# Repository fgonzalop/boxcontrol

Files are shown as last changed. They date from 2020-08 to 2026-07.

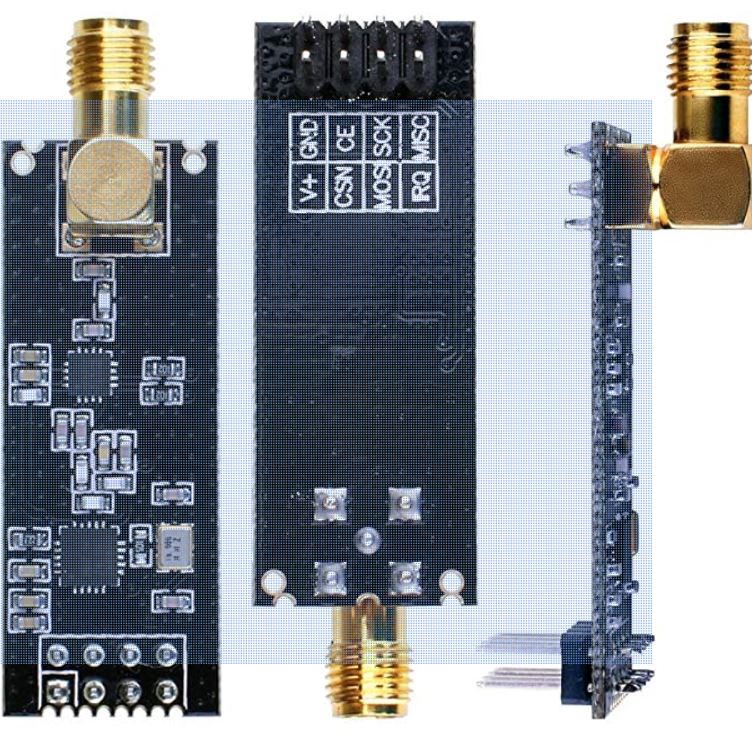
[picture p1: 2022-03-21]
nrf24_antena.JPG

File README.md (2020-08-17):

# BoxDomotic
Se almacenan los ejecutables de los nodos que estarán conectados por toda la vivienda.

Se almacena el GW (gateway) que cambia de MQTT a MESH(RF24) y viceversa.

Se define la red para que el GW pueda definir todas las rutas, con un NodeId y el ID de la transacción.

Se almacenan los ejecutables para hacer la calefacción, cerrado persianas, despertar, etc.. donde se automatiza.

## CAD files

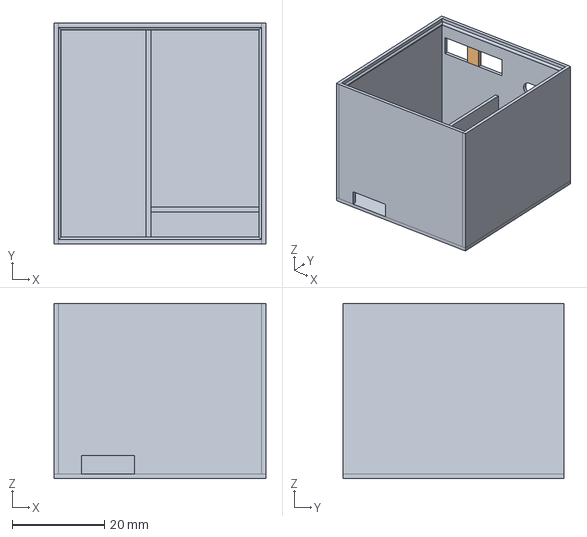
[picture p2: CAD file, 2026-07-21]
100CB001.FCStd
46.0 x 48.0 x 38.0 mm
100CB001
PilarSoporte

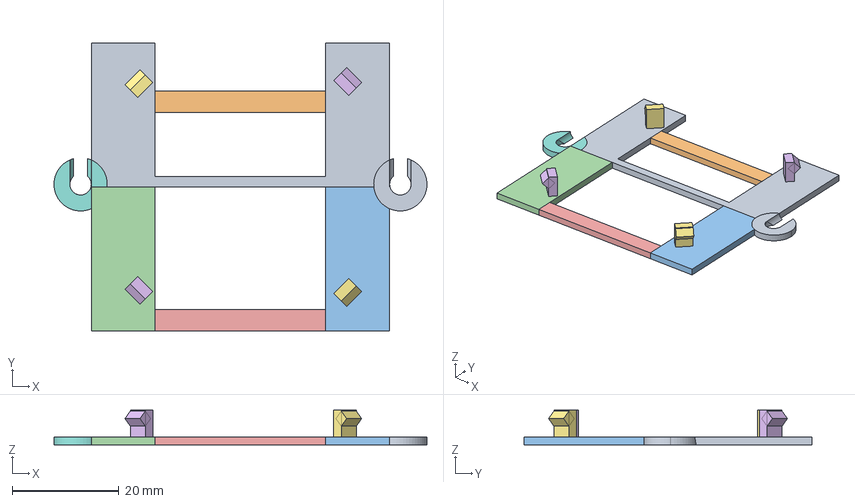
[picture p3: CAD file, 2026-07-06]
100CB011.FCStd
70.0 x 54.0 x 6.50 mm
Soporte
Barra001
Barra002
Barra003
Fusion014 (Mirror #4)

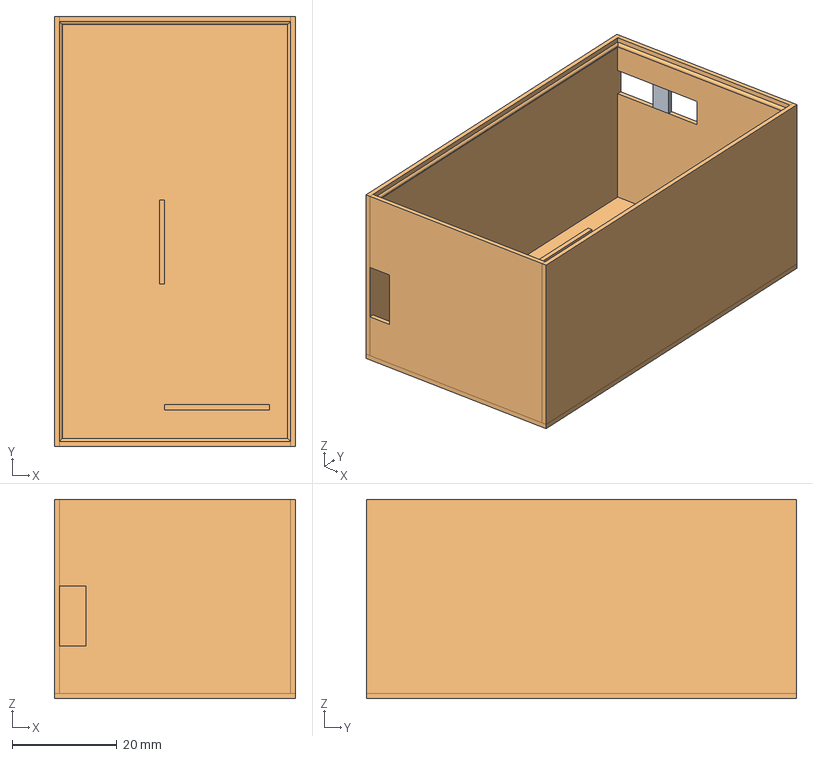
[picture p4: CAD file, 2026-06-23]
100CB006.FCStd
46.0 x 82.0 x 38.0 mm
PilarSoporte
100CB006

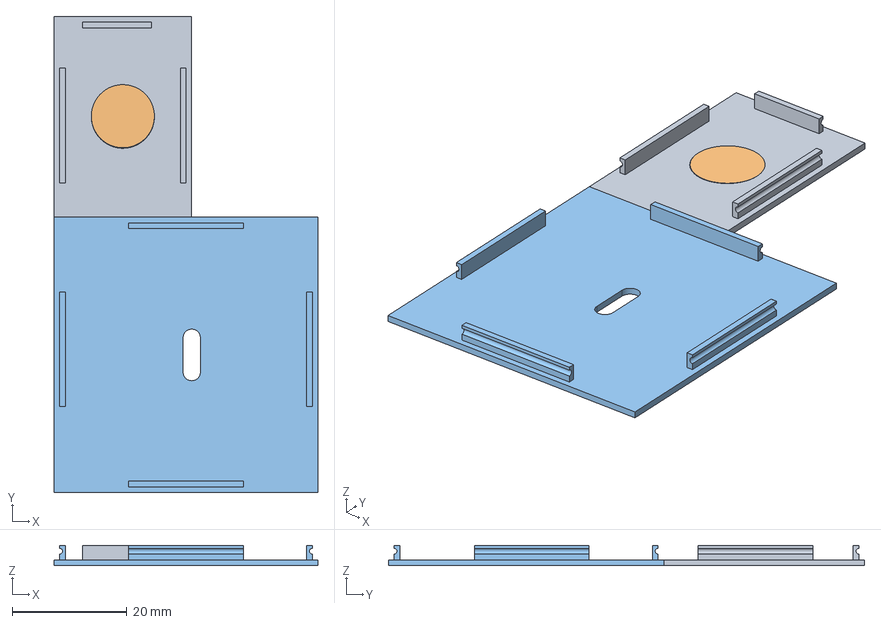
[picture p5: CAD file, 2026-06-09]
100CB009.FCStd
46.0 x 83.0 x 3.50 mm
100CB004
Logo
100CB002

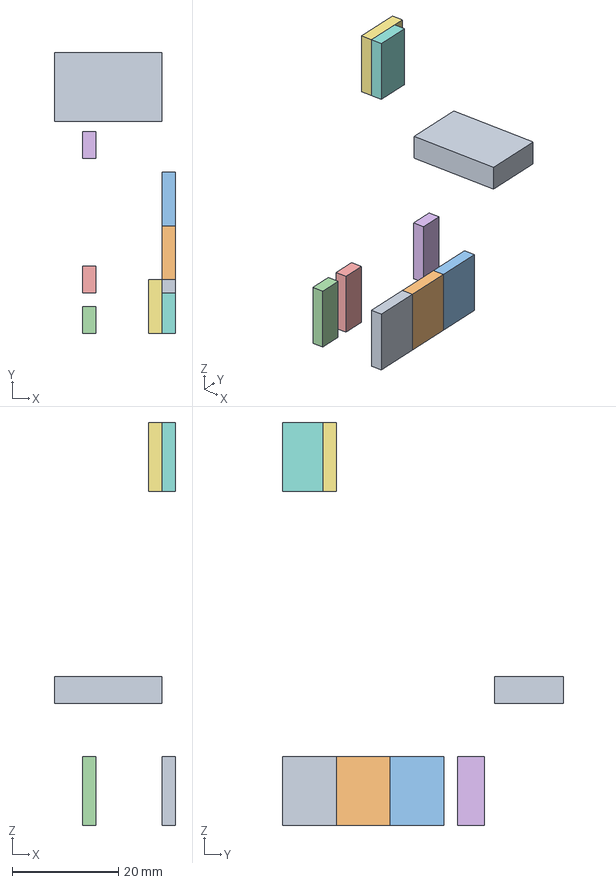
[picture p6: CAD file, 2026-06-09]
100CB005.FCStd
22.9 x 53.0 x 76.0 mm
Arduino1
Arduino2
Arduino3
Arduino4
Arduino5
Arduino6
RF24_4
RF24_3
Externo

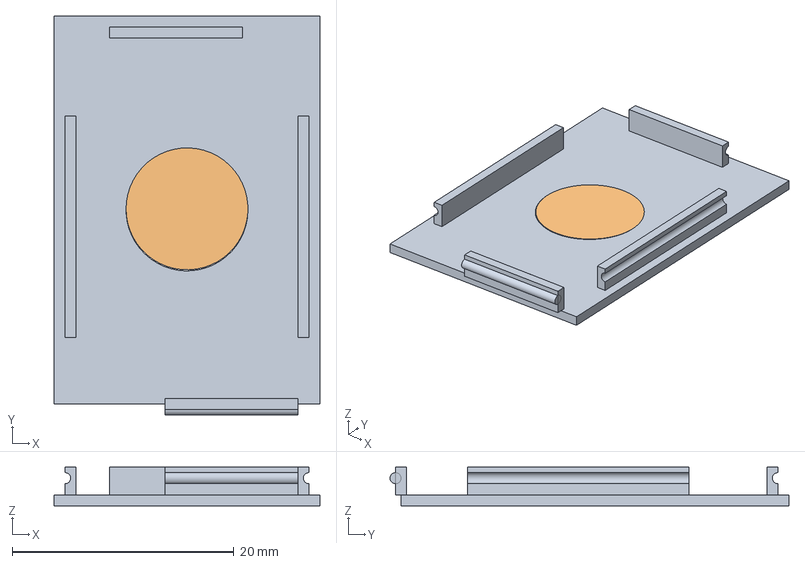
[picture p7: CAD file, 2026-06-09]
100CB004.FCStd
24.0 x 36.0 x 3.50 mm
Logo

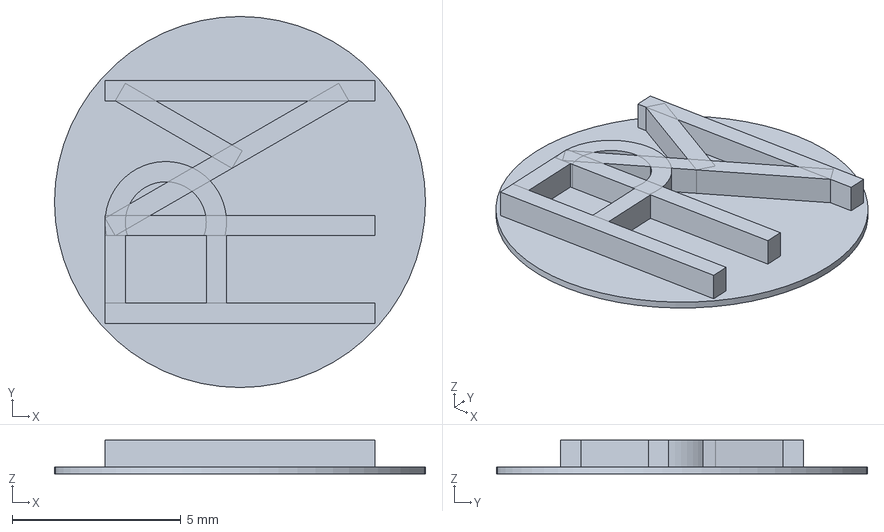
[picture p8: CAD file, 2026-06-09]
100CB007.FCStd
11.0 x 11.0 x 1.00 mm

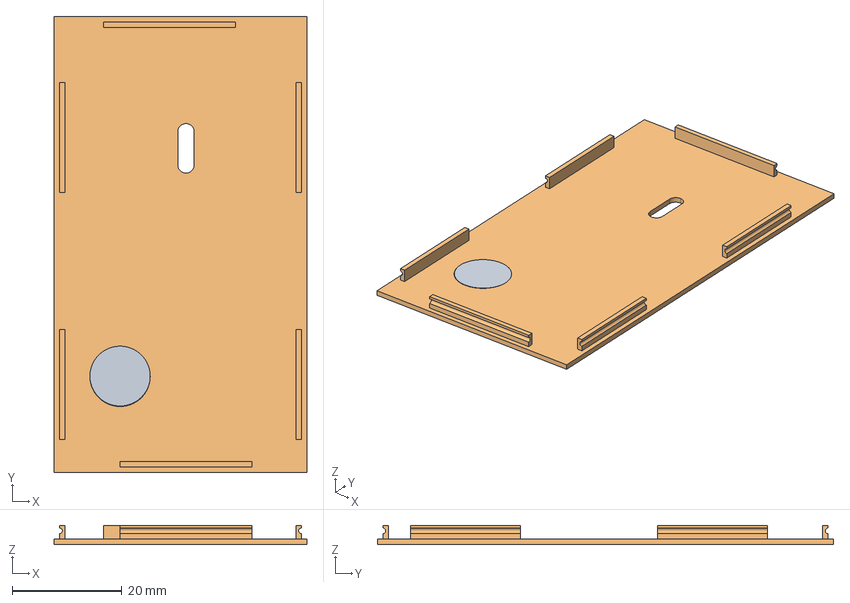
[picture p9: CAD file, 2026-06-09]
100CB008.FCStd
46.0 x 83.0 x 3.50 mm
Logo
100CB008

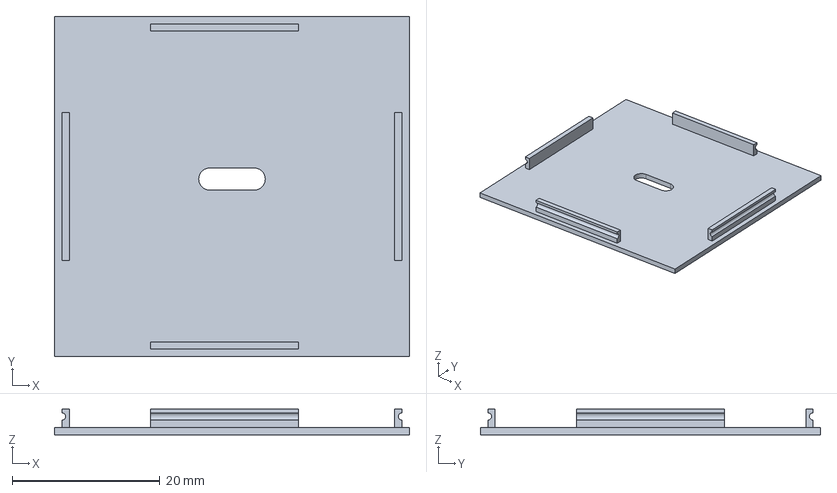
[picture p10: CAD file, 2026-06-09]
100CB002.FCStd
48.0 x 46.0 x 3.50 mm

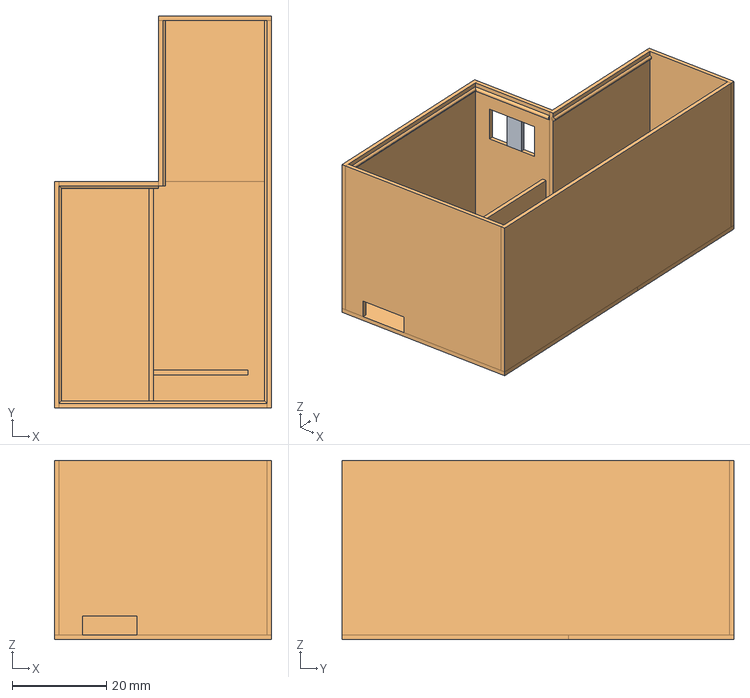
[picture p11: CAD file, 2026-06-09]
100CB003.FCStd
46.0 x 83.0 x 38.0 mm
PilarSoporte
100CB003

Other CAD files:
100CB001.stl
100CB003.stl
100CB004.stl
100CB006.stl
100CB007.stl
100CB008.stl
100CB009.stl
100CB011.stl

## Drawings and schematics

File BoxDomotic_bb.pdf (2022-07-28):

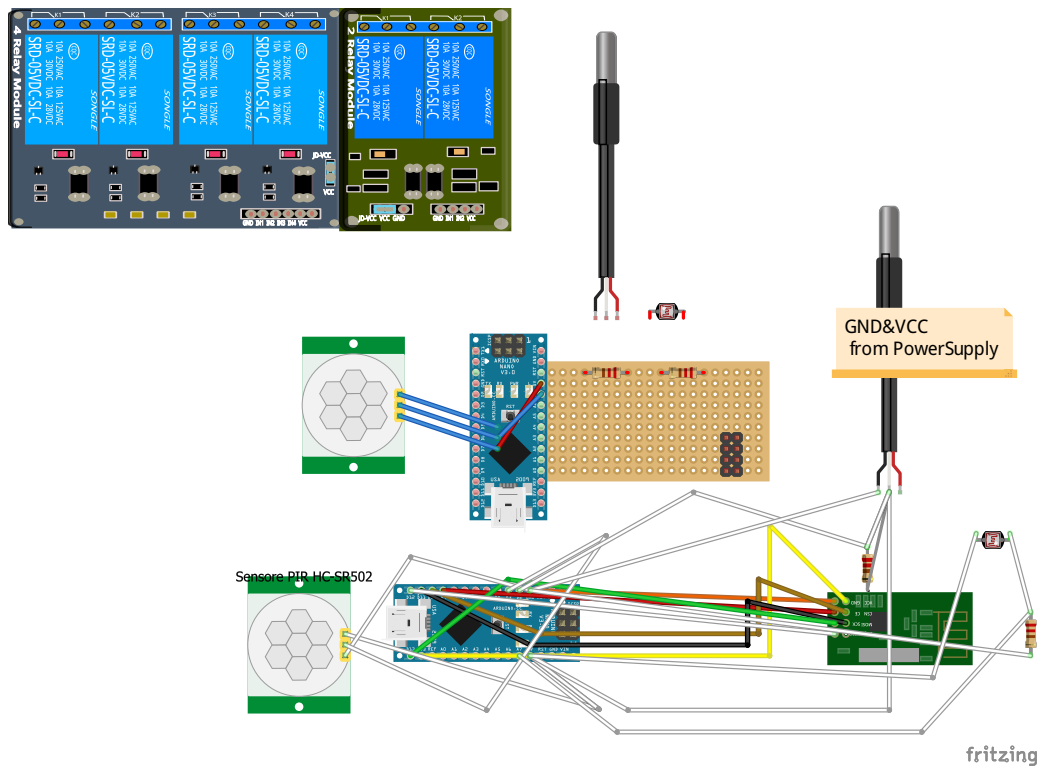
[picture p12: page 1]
GND&VCC from PowerSupply

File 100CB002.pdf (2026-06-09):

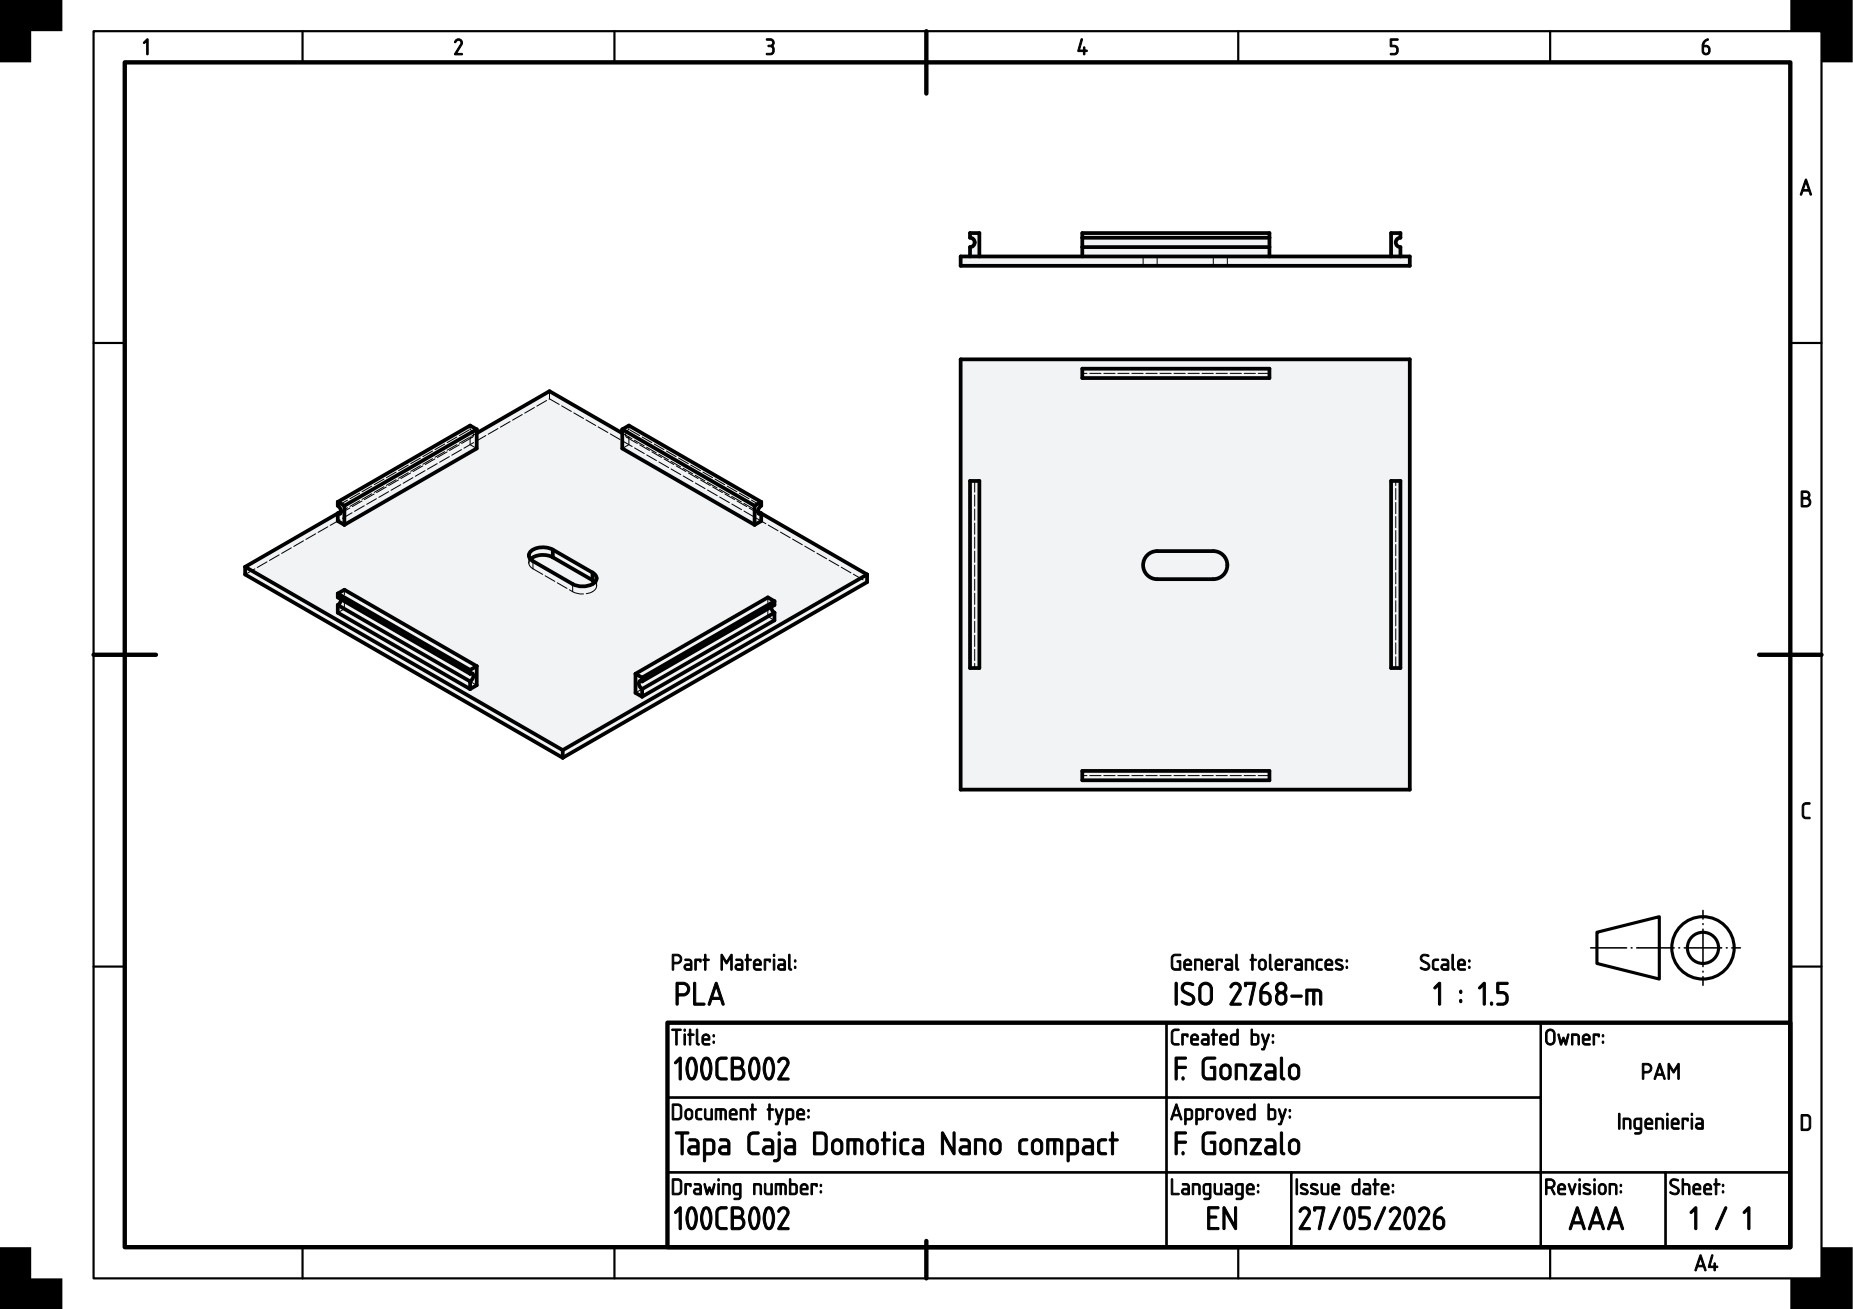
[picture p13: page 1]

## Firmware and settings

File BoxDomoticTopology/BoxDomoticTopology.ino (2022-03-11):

/*
* BoxDomotic Node to communicate with RPI and others
*/
#include <OneWire.h>
#include <EEPROM.h>
#include <SPI.h>
#include "RF24.h"
#include "BoxDomoticProtocol.h"

/* Hardware configuration: Set up nRF24L01 radio on SPI bus plus pins 9 & 10 */
RF24 radio(9,10);

int theRadioNumber;
volatile unsigned long thePIR_START = 0;
bool RxWaiting = true;
int theCurrentMessage = 0;
int theMaxMessages;
unsigned long last_time_message;

byte addresses[][6] = {"BoxDo","BoxDo"};

payload_t payload;
payload_t payload_r;
payload_t payload_original;
payload_t theRouting[10];

void setup() {
  int aIndex =0;

  Serial.begin(115200);
  Serial.println(F("****************************"));
  Serial.println(F("BoxDomotic Topology 1.0.0"));
  Serial.println(F("****************************"));

  theRadioNumber = EEPROM.read(RADIO_ID_ADDRESS);
  if (theRadioNumber == 0xFF)
  {
    theRadioNumber = 0xFE;
  }
  Serial.print("Radio ID ");
  Serial.println(theRadioNumber);
  
  radio.begin();

  // Set the PA Level low to prevent power supply related issues since this is a
 // getting_started sketch, and the likelihood of close proximity of the devices. RF24_PA_MAX is default.
  radio.setPALevel(RF24_PA_HIGH);
  
  // Open a writing and reading pipe on each radio, with opposite addresses
  radio.openWritingPipe(addresses[1]);
  radio.openReadingPipe(1,addresses[0]);

  int theMasterTxPin = EEPROM.read(MASTER_TX_PIN);
  if (theMasterTxPin == 1)
  {
    RxWaiting = false;  
  }
  else
  {
    RxWaiting = true;
    radio.startListening();
  }
  Serial.print("Master Rx:");
  Serial.println(RxWaiting);

  /* Nivel 1 */
  for (aIndex = 1; aIndex <10; aIndex++)
  {
    if (aIndex == theRadioNumber)
    { 
      aIndex++;
    }
    
    theRouting[theCurrentMessage].messageId = 100;
    theRouting[theCurrentMessage].hop1      = aIndex;
    theRouting[theCurrentMessage].origen    = theRadioNumber;
    theRouting[theCurrentMessage].action.action1 = REQUEST_PIR_ACTION; 
    theRouting[theCurrentMessage].action.action2 = SUCCESS_ANSWER; 
    theRouting[theCurrentMessage].hop2    = 0;
    theRouting[theCurrentMessage].hop3    = 0;
    theRouting[theCurrentMessage].hop4    = 0;
    theRouting[theCurrentMessage].hop5    = 0;
    theRouting[theCurrentMessage].hop6    = 0;
    theRouting[theCurrentMessage].hop7    = 0;
    theRouting[theCurrentMessage].hop_reply1 = theRadioNumber;
    theRouting[theCurrentMessage].hop_reply2 = 0;
    theRouting[theCurrentMessage].hop_reply3 = 0;
    theRouting[theCurrentMessage].hop_reply4 = 0;
    theRouting[theCurrentMessage].hop_reply5 = 0;
    theRouting[theCurrentMessage].hop_reply6 = 0;
    theRouting[theCurrentMessage].hop_reply7 = 0;
  
    Serial.print("TX payload:");
    Serial.print(theRouting[theCurrentMessage].messageId);
    Serial.print(" ");
    Serial.print(theRouting[theCurrentMessage].origen);
    Serial.print(" ");
    Serial.print(theRouting[theCurrentMessage].hop1);
    Serial.print(" ");
    Serial.print(theRouting[theCurrentMessage].hop2);
    Serial.print(" ");
    Serial.print(theRouting[theCurrentMessage].hop3);
    Serial.print(" ");
    Serial.print(theRouting[theCurrentMessage].hop4);
    Serial.print(" ");
    Serial.print(theRouting[theCurrentMessage].hop5);
    Serial.print(" ");
    Serial.print(theRouting[theCurrentMessage].hop6);
    Serial.print(" ");
    Serial.print(theRouting[theCurrentMessage].hop7);
    Serial.print(" ");
    Serial.print(theRouting[theCurrentMessage].action.action1);
    Serial.print(" ");
    Serial.print(theRouting[theCurrentMessage].action.action2);
    Serial.print(" ");
    Serial.print(theRouting[theCurrentMessage].action.action3);
    Serial.print(" ");
    Serial.print(theRouting[theCurrentMessage].action.action4);
    Serial.print(" ");
    Serial.print(theRouting[theCurrentMessage].hop_reply1);
    Serial.print(" ");
    Serial.print(theRouting[theCurrentMessage].hop_reply2);
    Serial.print(" ");
    Serial.print(theRouting[theCurrentMessage].hop_reply3);
    Serial.print(" ");
    Serial.print(theRouting[theCurrentMessage].hop_reply4);
    Serial.print(" ");
    Serial.print(theRouting[theCurrentMessage].hop_reply5);
    Serial.print(" ");
    Serial.print(theRouting[theCurrentMessage].hop_reply6);
    Serial.print(" ");
    Serial.print(theRouting[theCurrentMessage].hop_reply7);
  
    radio.write( &theRouting[theCurrentMessage], sizeof(payload_t) );              // Send the final one back.
    
    Serial.println(" OK");

    delay (500); 
  } 
  /* Nivel 2 */
  for (int route = 1; route <10; route++)
  {
    if (route == theRadioNumber)
    {
       route++;  
    }
    for (aIndex = 1; aIndex <10; aIndex++)
    {
      if ((aIndex == theRadioNumber) || (aIndex == route))
      { 
        aIndex++;
      }
      
      theRouting[theCurrentMessage].messageId = 102;
      theRouting[theCurrentMessage].hop1      = route;
      theRouting[theCurrentMessage].origen    = theRadioNumber;
      theRouting[theCurrentMessage].action.action1 = REQUEST_PIR_ACTION; 
      theRouting[theCurrentMessage].action.action2 = SUCCESS_ANSWER; 
      theRouting[theCurrentMessage].hop2    = aIndex;
      theRouting[theCurrentMessage].hop3    = 0;
      theRouting[theCurrentMessage].hop4    = 0;
      theRouting[theCurrentMessage].hop5    = 0;
      theRouting[theCurrentMessage].hop6    = 0;
      theRouting[theCurrentMessage].hop7    = 0;
      theRouting[theCurrentMessage].hop_reply1 = theRadioNumber;
      theRouting[theCurrentMessage].hop_reply2 = 0;
      theRouting[theCurrentMessage].hop_reply3 = 0;
      theRouting[theCurrentMessage].hop_reply4 = 0;
      theRouting[theCurrentMessage].hop_reply5 = 0;
      theRouting[theCurrentMessage].hop_reply6 = 0;
      theRouting[theCurrentMessage].hop_reply7 = 0;
    
      Serial.print("TX payload:");
      Serial.print(theRouting[theCurrentMessage].messageId);
      Serial.print(" ");
      Serial.print(theRouting[theCurrentMessage].origen);
      Serial.print(" ");
      Serial.print(theRouting[theCurrentMessage].hop1);
      Serial.print(" ");
      Serial.print(theRouting[theCurrentMessage].hop2);
      Serial.print(" ");
      Serial.print(theRouting[theCurrentMessage].hop3);
      Serial.print(" ");
      Serial.print(theRouting[theCurrentMessage].hop4);
      Serial.print(" ");
      Serial.print(theRouting[theCurrentMessage].hop5);
      Serial.print(" ");
      Serial.print(theRouting[theCurrentMessage].hop6);
      Serial.print(" ");
      Serial.print(theRouting[theCurrentMessage].hop7);
      Serial.print(" ");
      Serial.print(theRouting[theCurrentMessage].action.action1);
      Serial.print(" ");
      Serial.print(theRouting[theCurrentMessage].action.action2);
      Serial.print(" ");
      Serial.print(theRouting[theCurrentMessage].action.action3);
      Serial.print(" ");
      Serial.print(theRouting[theCurrentMessage].action.action4);
      Serial.print(" ");
      Serial.print(theRouting[theCurrentMessage].hop_reply1);
      Serial.print(" ");
      Serial.print(theRouting[theCurrentMessage].hop_reply2);
      Serial.print(" ");
      Serial.print(theRouting[theCurrentMessage].hop_reply3);
      Serial.print(" ");
      Serial.print(theRouting[theCurrentMessage].hop_reply4);
      Serial.print(" ");
      Serial.print(theRouting[theCurrentMessage].hop_reply5);
      Serial.print(" ");
      Serial.print(theRouting[theCurrentMessage].hop_reply6);
      Serial.print(" ");
      Serial.print(theRouting[theCurrentMessage].hop_reply7);
    
      radio.write( &theRouting[theCurrentMessage], sizeof(payload_t) );              // Send the final one back.
      
      Serial.println(" OK");
  
      delay (500); 
    }
  } 
}

/*
 * PIR_ISR
 */
void PIR_ISR()
{
   thePIR_START = millis();
}

/*
 * Procedure loop
 *    Se lee la parte de RF los datos.
 *    Se procesa y se manda ANSWER y PERFORM (si es diferido)
 */
void loop() 
{
	
} // Loop

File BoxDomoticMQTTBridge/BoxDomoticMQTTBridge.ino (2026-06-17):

//#include <ESP32HTTPUpdateServer.h>
#include <EspMQTTClient.h>

#include <nRF24L01.h>
#include <printf.h>
#include <RF24.h>
#include <RF24_config.h>
#include "ArduinoJson.h"
#include "BoxDomoticProtocol.h"

/*
 Basic ESP8266 MQTT example

 This sketch demonstrates the capabilities of the pubsub library in combination
 with the ESP8266 board/library.

 It connects to an MQTT server then:
  - publishes "hello world" to the topic "outTopic" every two seconds
  - subscribes to the topic "inTopic", printing out any messages
    it receives. NB - it assumes the received payloads are strings not binary
  - If the first character of the topic "inTopic" is an 1, switch ON the ESP Led,
    else switch it off

 It will reconnect to the server if the connection is lost using a blocking
 reconnect function. See the 'mqtt_reconnect_nonblocking' example for how to
 achieve the same result without blocking the main loop.

 To install the ESP8266 board, (using Arduino 1.6.4+):
  - Add the following 3rd party board manager under "File -> Preferences -> Additional Boards Manager URLs":
       http://arduino.esp8266.com/stable/package_esp8266com_index.json
  - Open the "Tools -> Board -> Board Manager" and click install for the ESP8266"
  - Select your ESP8266 in "Tools -> Board"

*/

#include <ESP8266WiFi.h>
//#include <PubSubClient.h>

// Update these with values suitable for your network.

const char* ssid = "desconectada";
const char* password = "casapepe.";
const char* mqtt_server = "192.168.1.103";

WiFiClient espClient;
PubSubClient client(espClient);
long lastMsg = 0;
char msg[51];
int value = 0;
/* Hardware configuration: Set up nRF24L01 radio on SPI bus plus pins 9 & 10 */
RF24 radio(2,4);
payload_t payload_r;
byte addresses[][6] = {"BoxDo","BoxDo"};
int theCurrentMessage = 0;
int theMaxMessages;
payload_t theRouting[10];
int theRadioNumber = 8;

void setup_wifi() {

  delay(10);
  // We start by connecting to a WiFi network
  Serial.println();
  Serial.print("Connecting to ");
  Serial.println(ssid);

  WiFi.begin(ssid, password);

  while (WiFi.status() != WL_CONNECTED) {
    delay(500);
    Serial.print(".");
  }

  randomSeed(micros());
  Serial.println("");
  Serial.println("*********************");
  Serial.println("BoxDomotic Master 1.0.0");
  Serial.println("*********************");
  Serial.println("");
  Serial.println("WiFi connected");
  Serial.println("IP address: ");
  Serial.println(WiFi.localIP());

  radio.begin();

  // Set the PA Level low to prevent power supply related issues since this is a
 // getting_started sketch, and the likelihood of close proximity of the devices. RF24_PA_MAX is default.
  radio.setPALevel(RF24_PA_MAX);
  
  // Open a writing and reading pipe on each radio, with opposite addresses
  radio.openWritingPipe(addresses[1]);
  radio.openReadingPipe(1,addresses[0]);
    
  // Start the radio listening for data
  //radio.startListening();
  printf_begin();
  radio.printDetails();
}

void callback(char* topic, byte* payload, unsigned int length) {
  Serial.print("Message arrived [");
  Serial.print(topic);
  Serial.print("] ");
  for (int i = 0; i < length; i++) {
    Serial.print((char)payload[i]);
  }
  Serial.println();

  if (payload[1] == 'f')
  {
    theRouting[3].action.action1 = REQUEST_ON_RELAY_ACTION; 
    theRouting[3].action.action2 = 1; 
  }else
  {
    theRouting[3].action.action1 = REQUEST_OFF_RELAY_ACTION; 
    theRouting[3].action.action2 = 1; 
  }
  
  
  // Switch on the LED if an 1 was received as first character
  if ((char)payload[0] == '1') {
    digitalWrite(BUILTIN_LED, LOW);   // Turn the LED on (Note that LOW is the voltage level
    // but actually the LED is on; this is because
    // it is active low on the ESP-01)
  } else {
    digitalWrite(BUILTIN_LED, HIGH);  // Turn the LED off by making the voltage HIGH
  }

}

void reconnect() {
  String IP = WiFi.localIP().toString();
  // Loop until we're reconnected
  while (!client.connected()) {
    Serial.print("Attempting MQTT connection...");
    // Create a random client ID
    String clientId = "ESP8266Client-";
    clientId += String(random(0xffff), HEX);
    String listOfNodes = " {\"aerotermia_1\": \"relays-a0002\", \"patioBajo\": \"box-a0004\", \"salon\": \"box-a0002\", \"lavadero\": \"box-a0009\"}"; 
    // Attempt to connect
    if (client.connect(clientId.c_str())) {
      Serial.println("connected");
      // Once connected, publish an announcement...
      client.publish("boxdomotics/boxmaster/announce", "ESP8266 up", false);
      client.publish("boxdomotics/boxmaster/ip", IP.c_str(), false);
      client.publish("boxdomotics/boxmaster/nodes", listOfNodes.c_str(), false);
      // client.publish("boxdomotics/box-a0004/temperature", "Starting", false);
      // ... and resubscribe
      //client.subscribe("shellies/shellybutton1-C45BBE6BA510/input_event/0");
      client.subscribe("boxdomotics/relays-a0002/relay/0/command");
      client.subscribe("test/relay/1/command");
    } else {
      Serial.print("failed, rc=");
      Serial.print(client.state());
      Serial.println(" try again in 5 seconds");
      // Wait 5 seconds before retrying
      delay(5000);
    }
  }
}
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

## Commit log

2020-08-17 Recepcion de mensajes mqtt.
2020-08-25 Lectura de json con la red de los nodos.
2020-09-20 Relay funcionando 2(relay) 3(final)
2020-09-22 Creado el Routing con timeout dependiendo de los saltos. Añadido fichero definiciones.
2020-09-22 Inclusión de Radio Id a fuego comentada, hasta que se pueda comandar OTA.
2020-09-24 Implementacion mecanismos ANSWER/PERFORM de una temperatura.
2020-10-03 Actualizacion y alineacion con el protocolo.
2020-10-03 Generacion de ficheros de configuracion topologia y mensajes. Falta TDMA (lista de mensajes secuencia y delays)
2020-10-28 Version que toma de los json y construye un mensaje para mandar. Solo coge el (0). Solo mandad un mensaje no coge TDMA.
2020-10-30 Implementada la lectura de json de acciones.. no todas. Mostrado en ARDUINO de datos (Accion y Accion2).
2021-01-05 Inclusion de los parametros en /Calefaccion/planta1
2021-01-05 Inclusión de la version instalada.
2021-01-05 Inclusion de los nodos 1 y 3.
2021-04-03 Inclusión del pin de temperatura. D4.
2021-04-04 Inclusión de PIR-D3 conectada a la interrupción.
2021-04-04 Inclusión de LUX pin A7
2021-12-26 Creación de aplicación para guardar archivos de configuración JSON traducido a .h
2021-12-26 Corregido el pb de las temperaturas diferidas.
2021-12-27 Implementación y prueba de LUX. El valor devuelto es el máximo con fondo de escala de 255 = 5 V
2021-12-28 Implementación para subida y bajada. Se comprueba que hay siempre 2,5s entre ambas.
2021-12-28 Implementada PIR feature con la devolución desde la última detección. Al contestar se resetea el valor.
    [BoxDomoticNode.ino]
2021-12-28 Valores de Calefacción P0 para las pruebas.
2021-12-28 Error al escribir los PINs de los relés.
    [BoxDomoticNode.ino, InitNode.ino]
2021-12-28 Probado Módulo 1 con el HW del módulo 2.
2021-12-28 Versión de Calefaccion P1 completada, vía nodo 3.
2021-12-28 Corregido la RASPBERRY.
2021-12-29 Añadido modulo de pruebas. Añadido a NODO 2, TEMPERATURA a PIN 4.
2021-12-30 Añadido el ejecutable. Preparando el interfaz de ROLLER (persiana).
2021-12-30 Cambiado en Raspberry.
2022-01-03 Action3 en la respuesta, para responder la temperatura en action3 (los decimales) y en action2 (el entero-sin multiplicar *2)
2022-01-03 Creación de la temperatura INT=action2 y DEC=action3. Falta probarlo.
2022-02-15 Inclusión del node 4 para temperatura en lavadero.
2022-02-17 Creacion del nodo de la buhardilla.
2022-03-01 Inclusión de un MasterNode para recibir y otro para transmitir. Inclusión en BoxDomotic.h de la posición para distinguir el valor de Rx o Tx en master. Modificado el InitNode para soportar el nuevo v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
2022-03-01 Tx dos mensajes cambiando sólo el Hop1.
2022-03-01 Limpieza de código. Inclusión de 2 mensajes en la cola.
2022-03-01 Limpieza de código.
2022-03-03 Actualizacion del protocolo y actualización de equipos. Añadido nodo 9.
2022-03-08 Inclusión de la potencia máxima.
2022-03-08 Despliegue version 2.0.2 para medir tiempos de muestreo.
2022-03-11 Inclusión de un mensaje nuevo para probar el nodo2 (calefacción).
2022-03-15 Inclusión del mensaje de NEIGHBOUR
2022-03-21 Mostrar datos de RF. Diseño de la PCB a soldar.
    [BoxDomotic.fzz]
2022-03-21 PCB mas detallada.
2022-03-29 Actualización de la tarjeta PCB y las conexiones.
    [BoxDomotic.fzz]
2022-07-28 Creación del BoxDomoticMaster en ESP8266 para publicar y controlar el MQTT bridge.
    [BoxDomotic.fzz]
2022-07-28 Script para recoger valores de SUN2000 y publicarlos MQTT.
2022-07-28 Eliminación de PRINTS.
2026-06-09 Starting testing/setup nodes
    [100CB001.FCStd, 100CB001.stl, 100CB002.FCStd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]
2026-06-17 Testing RF, Relay and TRA/LUX
2026-06-23 ESP32 box final version
    [100CB006.FCStd, 100CB006.stl]
2026-06-27 Adding numbers and structure and MICRO boxes bigger
    [100CB001.FCStd, 100CB001.stl]
2026-07-06 Adding tapa for PIR
    [100CB011.FCStd, 100CB011.stl]
2026-07-21 Small changes, ID for sotano
    [100CB001.FCStd]
2026-11-05 Adding the ESP32 with display
2026-11-05 Changing the icons ESP32
